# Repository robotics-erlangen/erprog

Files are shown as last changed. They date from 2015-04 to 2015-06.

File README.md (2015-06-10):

# ERPROG
This is a JTAG-Programmer developed by the Robot Soccer Team ER-Force from Erlangen, Germany.
The device is using a FTDI chip for communication and a digital isolator for the target.
All necessary files to build and control this device can be found within this repository.

The benefits of this hardware are the easy USB connection with EMC protection and over-current protection. Furthermore the standard JTAG output with a complete isolation up to 4kV. The target isolation is done by two ISO7231M from Texas Instruments. This device also does a voltage translation, which adapts to the target voltage-level. Working is guaranteed from 3.2 to 5.4V.
With this circuit the computer is never effected, if the programming target fails in any way.

Project origin: https://www.robotics-erlangen.de/publications/jtag-programmer

## Hardware

The PCB is designed with EAGLE. The schematic can be found in `erprog_1504-1.sch` and the board in `erprog_1504-1.brd`. The dimension of the PCB is 850mil x 2300mil.

The main ICs are

1.  FT4232HL does the USB to JTAG conversation
2.  ISO7231 is the digital isolator

## Software

The software readme is in https://github.com/robotics-erlangen/erprog/tree/master/software

## Computer connection

**via USB**

The device is connected via a Mini-USB plug to the computer.

## Target connection

**via JTAG**

This hardware uses a JTAG standard connector with a 10 pin connector with the `CoreSight 10` pinout.
Follwoing the pinout is described based on a standard 10 pin 100mil plug with 2 rows.

1.  VTREF
2.  TMS
3.  GND
4.  TCK
5.  GND
6.  TDO
7.  NC
8.  TDI
9.  GND
10. nSRST

## ToDo

For the next release it is planned to allow the controlling of the isolator's enable-pin. Thus, the programmer can be put into high-impedance mode so it does not interfere with the target in normal operation.

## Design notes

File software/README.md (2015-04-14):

# ERPROG Software

## Setup

**Build OpenOCD:**

1.	Download OpenOCD 0.8.0 (MD5 6d83c34763a5f1d1ac7ad83c5a11f4fb) and install `libusb-1.0`
2.	Build using:

	```
	mkdir build && cd build
	../configure --enable-ftdi --prefix=../build-out
	```

**On Linux:**

1.	Install the udev config file `udev/99-robotics-usb-devices.rules`
2.	Copy into the folder `/etc/udev/rules.d/`

**Embedded Compiler / Debugger:**
Get GCC 4.9 from https://launchpad.net/gcc-arm-embedded

**Create config files:**

1.	Create board file and flash configuration (see `board/*.cfg` and `flash/*.cfg`)
2.	Make sure to add

	```
	source [find interface/oocdlink-erforce2014.cfg]
	reset_config srst_only srst_nogate srst_push_pull
	```
	at the beginning

## Flashing     

*Tested on Linux and Mac OS X* 

1.	Connect connect the JTAG adapter with the board you want to flash and your USB port.
2.	Then run

	```
	cd JTAG-software
	${path/to/openocd} -c "debug_level 0" -s openocd -c "set ::ELF_FILE \"${path/to/elf-file}\"" -f flash/${CONFIG-NAME}.cfg
	```

**Troubleshooting:**
-	Check that the JTAG-adapter is connected to USB and the board
-	Check that the board is powered on
-	Check that the udev file (udev/99-robotics-usb-devices.rules) is installed
-	OpenOCD complains about "JTAG-DP OVERRUN" -> Resetting via SRST is not working, check that on the board JTAG SRST pin is connected with NRST pin of STM
-	Mac: „Error: libusb_claim_interface() failed with -3“. Run:
	```
	sudo kextunload -bundle com.apple.driver.AppleUSBFTDI
	```

## Debugging

*Only works on Linux*

1.	Flash the board with a build with **DEBUG symbols**!
2.	Start openocd for the board

	```
	cd JTAG-software
	${path/to/openocd} -c "debug_level 0" -s openocd -f board/${BOARD-NAME}.cfg
	```
3.	Connect to the debugger using Qt Creator:
	Debug > Start debugging > Attach to Remote Debug Server ...
	Set the following values:
	
	```
	Kit: Embedded
	Server port: 3333 (This attaches to the first cpu target, use 3334 for the second, ...)
	Local executable: the elf file in bin/firmware that was flashed
	```

The Kit has to be created before:

1.	Tools > Options ... > Build & Run > Kits
2.	Add a new kit with name `Embedded`, set device type to `Generic Linux Device`
3. 	Debugger > Edit...
	1. 	Path: `/usr/bin/arm-none-eabi-gdb`  (arm version of gdb with python), exectuable name could also be `arm-none-eabi-gdb-py`.
	2. 	Qt version: None

Have fun debugging! The debugger will attach to the running firmware. If you want
to debug the startup procedure, then edit the openocd configuration as described
in `openocd/board/all2014.cfg`

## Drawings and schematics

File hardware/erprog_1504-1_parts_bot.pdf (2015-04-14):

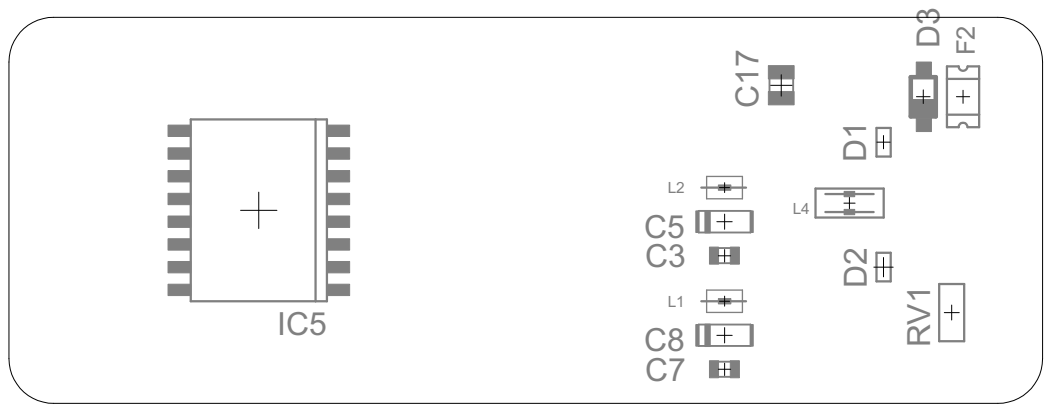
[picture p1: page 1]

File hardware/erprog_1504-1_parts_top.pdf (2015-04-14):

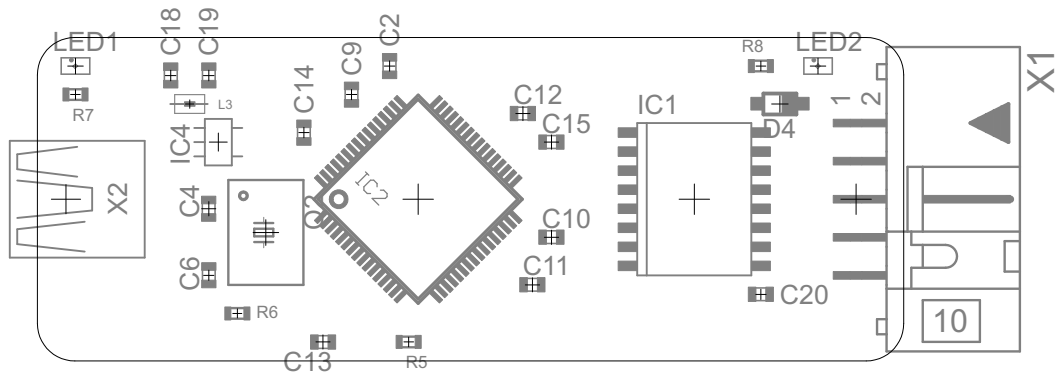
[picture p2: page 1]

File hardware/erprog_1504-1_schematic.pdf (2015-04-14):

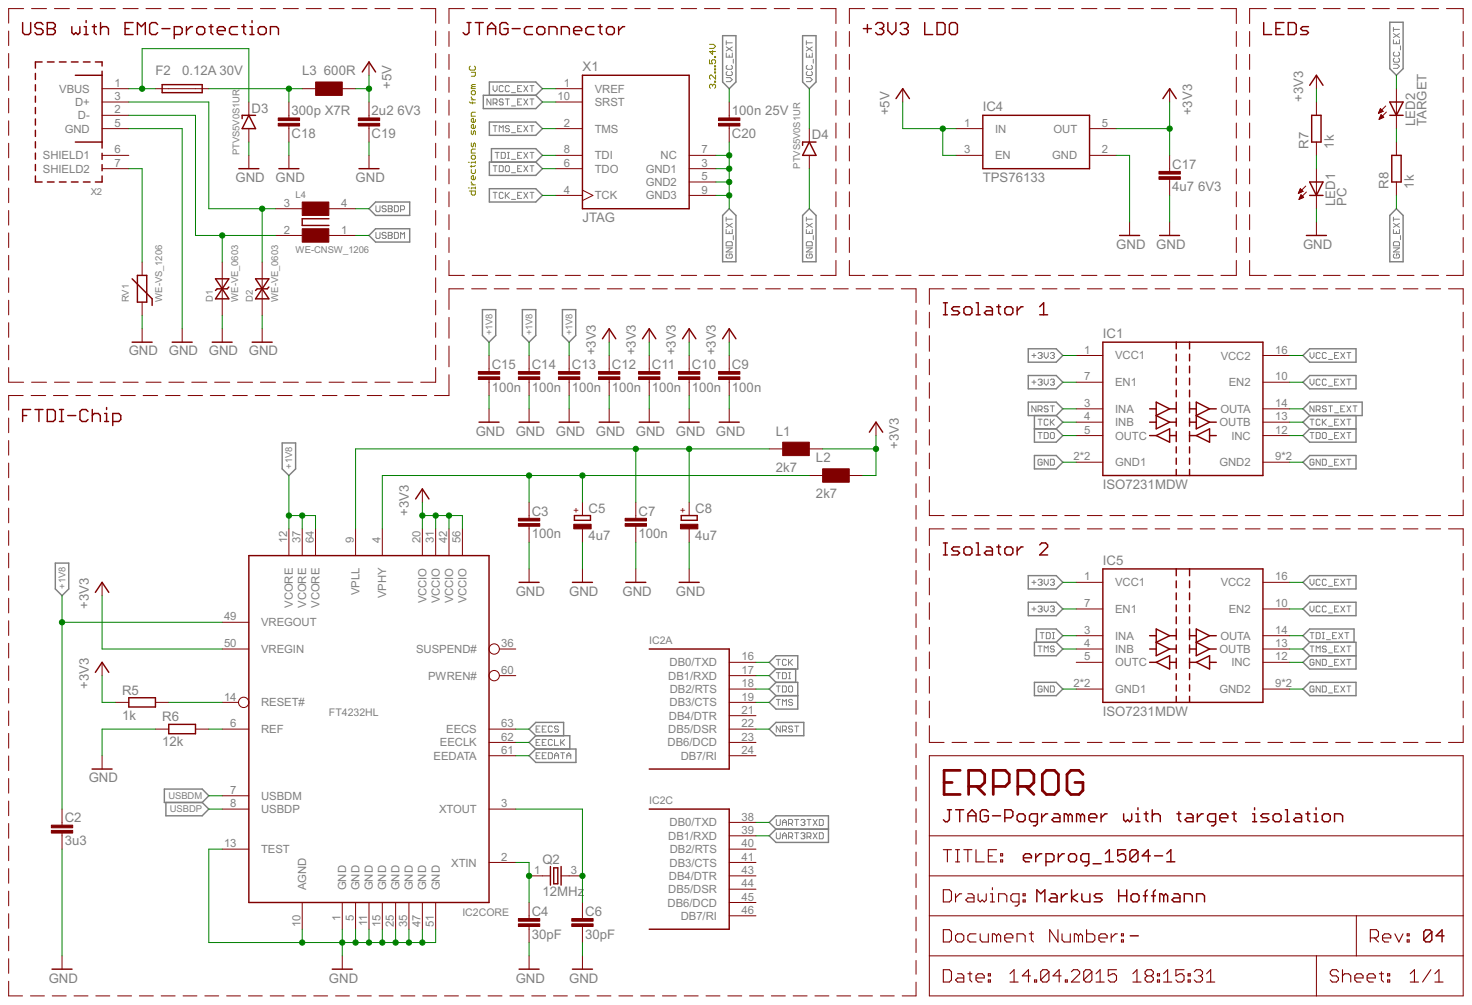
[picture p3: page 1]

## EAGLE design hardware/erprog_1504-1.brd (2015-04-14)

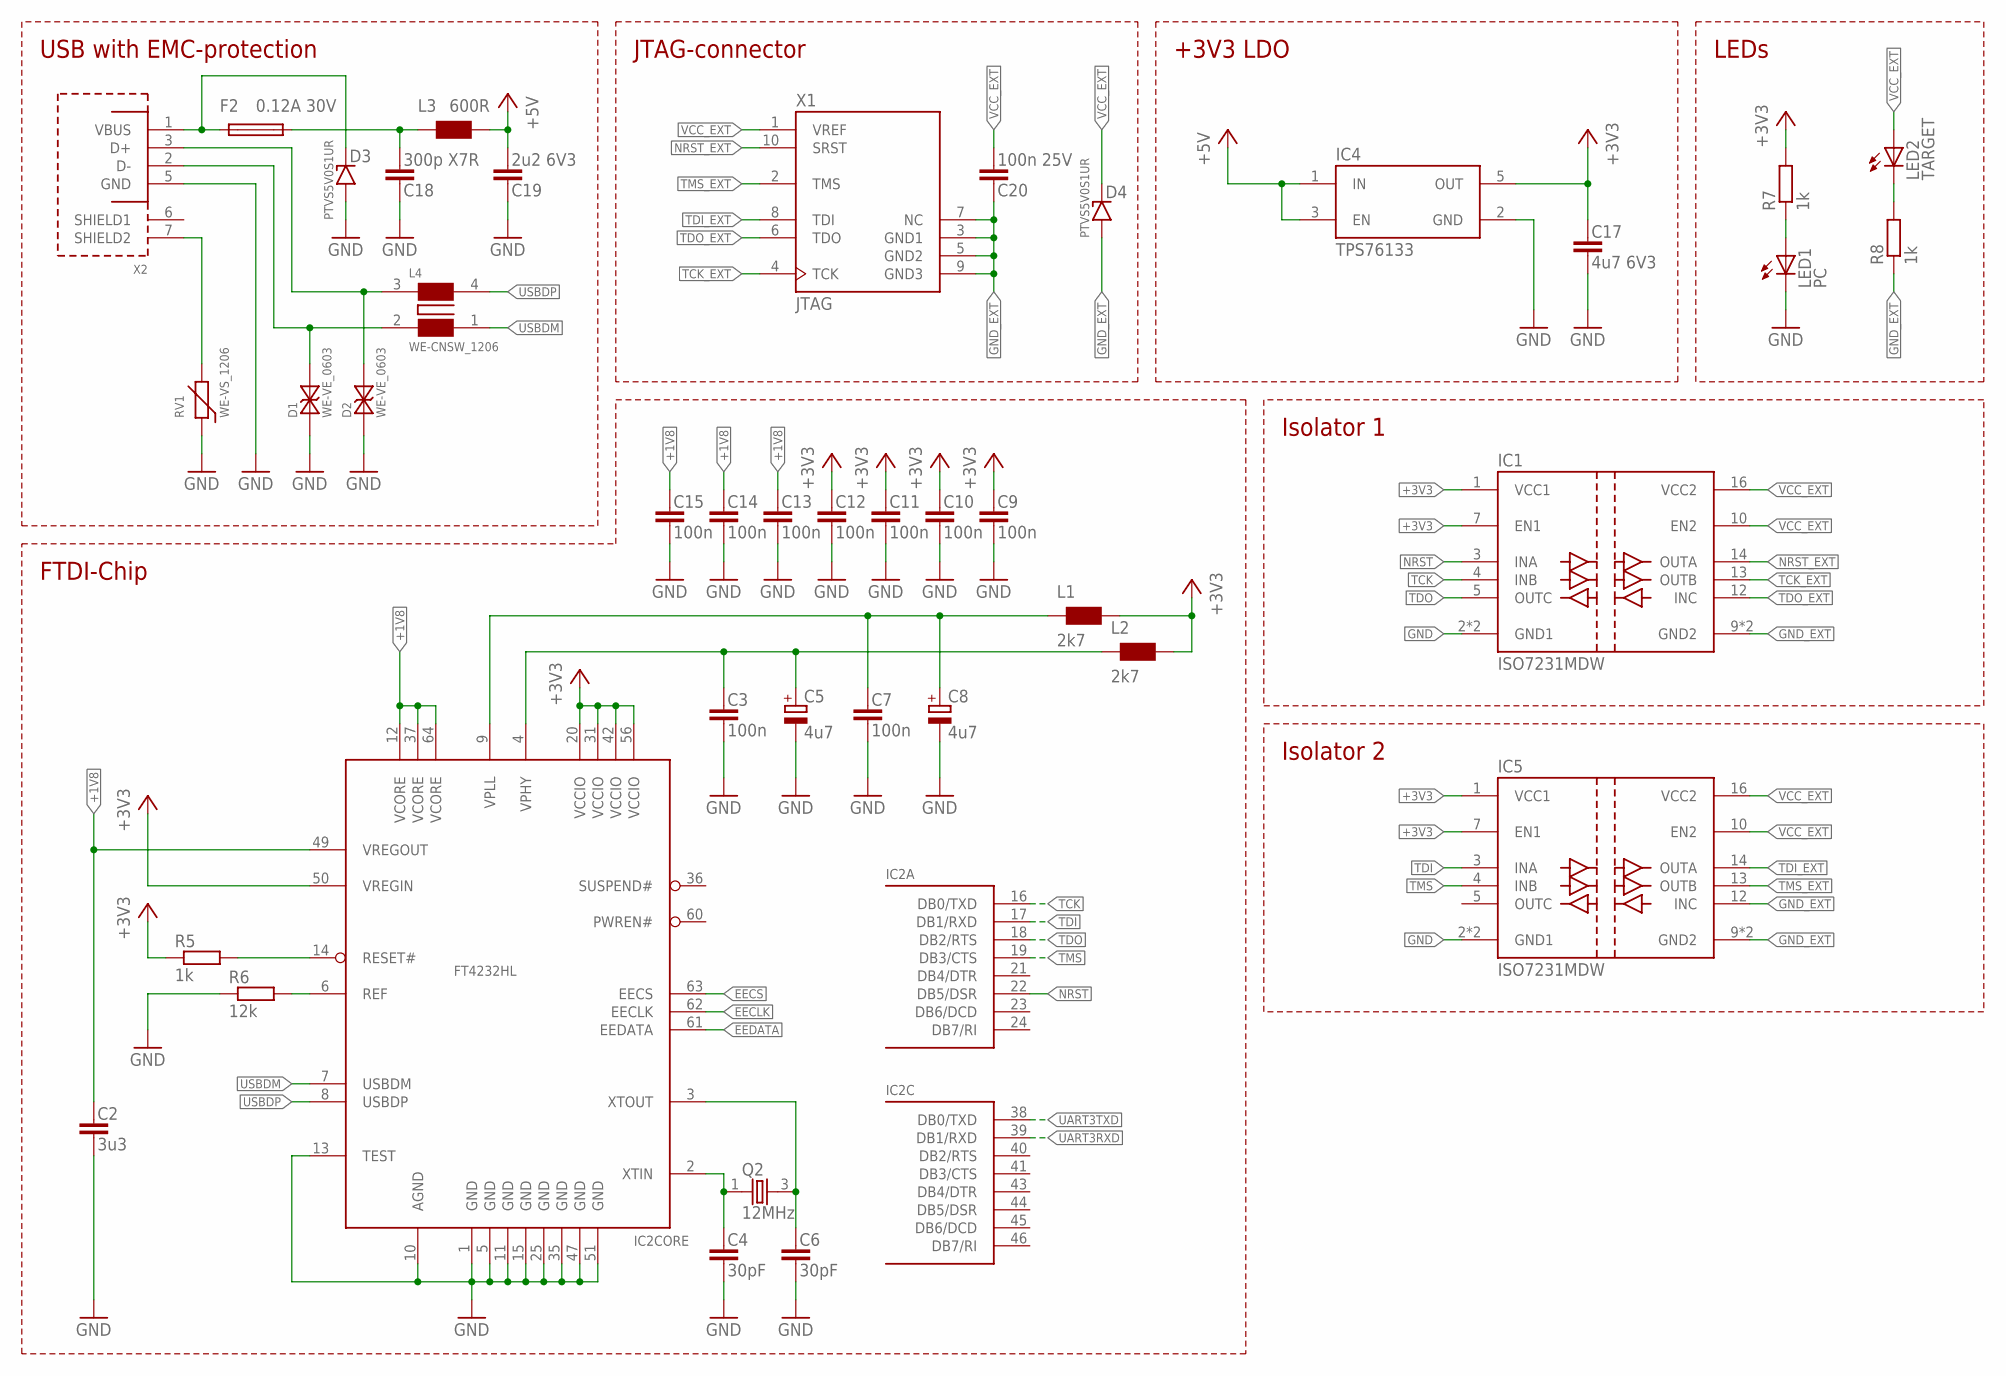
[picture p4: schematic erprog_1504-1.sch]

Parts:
C2: 3u3; C0603
C3, C7, C9, C10, C11, C12, C13, C14, C15: 100n; C0603
C4, C6: 30pF; C0603
C5, C8: 4u7; A/3216-18R
C17: 4u7 6V3; C0805
C18: 300p X7R; C0603
C19: 2u2 6V3; C0603
C20: 100n 25V; C0603
D1, D2: WE-VE_0603; WESURGE_0603
D3, D4: PTVS5V0S1UR; SOD123
F2: 0.12A 30V; MF-NSMF-1
IC1, IC5: ISO7231MDW; SO16_SOT162-1
IC2: FT4232HL; LQFP64
IC4: TPS76133; SOT-23-5
L1, L2: 2k7; 0805; FARNELL 1800366
L3: 600R; 0805
L4: WE-CNSW_1206
LED1: PC; SML0805
LED2: TARGET; SML0805
Q2: 12MHz; MQ
R5, R7, R8: 1k; R0603
R6: 12k; R0603
RV1: WE-VS_1206; WESURGE_1206
X1: JTAG; ML10R
X2: USB-SHIELD-MINI-B-BUCHSE-R-ASSMANN; USB-MINI-B-BUCHSE-R

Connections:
+1V8: C2.1, C13.1, C14.1, C15.1, IC2.12 (VCORE), IC2.37 (VCORE), IC2.49 (VREGOUT), IC2.64 (VCORE)
+3V3: C9.1, C10.1, C11.1, C12.1, C17.1, IC1.1 (VCC1), IC1.7 (EN1), IC2.20 (VCCIO), IC2.31 (VCCIO), IC2.42 (VCCIO), IC2.50 (VREGIN), IC2.56 (VCCIO), IC4.5 (OUT), IC5.1 (VCC1), IC5.7 (EN1), L1.2, L2.2, R5.1, R7.2
+5V: C19.2, IC4.1 (IN), IC4.3 (EN), L3.2
EECLK: IC2.62 (EECLK)
EECS: IC2.63 (EECS)
EEDATA: IC2.61 (EEDATA)
GND: C2.2, C3.2, C4.2, C5.-, C6.2, C7.2, C8.-, C9.2, C10.2, C11.2, C12.2, C13.2, C14.2, C15.2, C17.2, C18.1, C19.1, D1.2, D2.2, D3.A (ANODE), IC1.2 (GND1), IC1.8 (GND1), IC2.1 (GND), IC2.5 (GND), IC2.10 (AGND), IC2.11 (GND), IC2.13 (TEST), IC2.15 (GND), IC2.25 (GND), IC2.35 (GND), IC2.47 (GND), IC2.51 (GND), IC4.2 (GND), IC5.2 (GND1), IC5.8 (GND1), LED1.C, R6.1, RV1.1, X2.5 (GND)
GND_EXT: C20.1, D4.A (ANODE), IC1.9 (GND2), IC1.15 (GND2), IC5.9 (GND2), IC5.12 (INC), IC5.15 (GND2), R8.1, X1.3 (GND1), X1.5 (GND2), X1.7 (NC), X1.9 (GND3)
unnamed: D3.C (KATHODE), F2.1, X2.1 (VBUS)
unnamed: LED1.A, R7.1
unnamed: D1.1, L4.2, X2.2 (D-)
unnamed: RV1.2, X2.7 (SHIELD2)
unnamed: LED2.C, R8.2
unnamed: C18.2, F2.2, L3.1
unnamed: D2.1, L4.3 (4), X2.3 (D+)
unnamed: IC2.14 (RESET#), R5.2
unnamed: IC2.6 (REF), R6.2
unnamed: C3.1, C5.+, IC2.4 (VPHY), L2.1
unnamed: C7.1, C8.+, IC2.9 (VPLL), L1.1
unnamed: C6.1, IC2.3 (XTOUT), Q2.3 (2)
unnamed: C4.1, IC2.2 (XTIN), Q2.1
NRST: IC1.3 (INA), IC2.22 (DB5/DSR)
NRST_EXT: IC1.14 (OUTA), X1.10 (SRST)
TCK: IC1.4 (INB), IC2.16 (DB0/TXD)
TCK_EXT: IC1.13 (OUTB), X1.4 (TCK)
TDI: IC2.17 (DB1/RXD), IC5.3 (INA)
TDI_EXT: IC5.14 (OUTA), X1.8 (TDI)
TDO: IC1.5 (OUTC), IC2.18 (DB2/RTS)
TDO_EXT: IC1.12 (INC), X1.6 (TDO)
TMS: IC2.19 (DB3/CTS), IC5.4 (INB)
TMS_EXT: IC5.13 (OUTB), X1.2 (TMS)
UART3RXD: IC2.39 (DB1/RXD)
UART3TXD: IC2.38 (DB0/TXD)
USBDM: IC2.7 (USBDM), L4.1
USBDP: IC2.8 (USBDP), L4.4 (3)
VCC_EXT: C20.2, D4.C (KATHODE), IC1.10 (EN2), IC1.16 (VCC2), IC5.10 (EN2), IC5.16 (VCC2), LED2.A, X1.1 (VREF)

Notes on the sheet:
JTAG-connector
+3V3 LDO
LEDs
USB with EMC-protection
FTDI-Chip
Isolator 1
Isolator 2

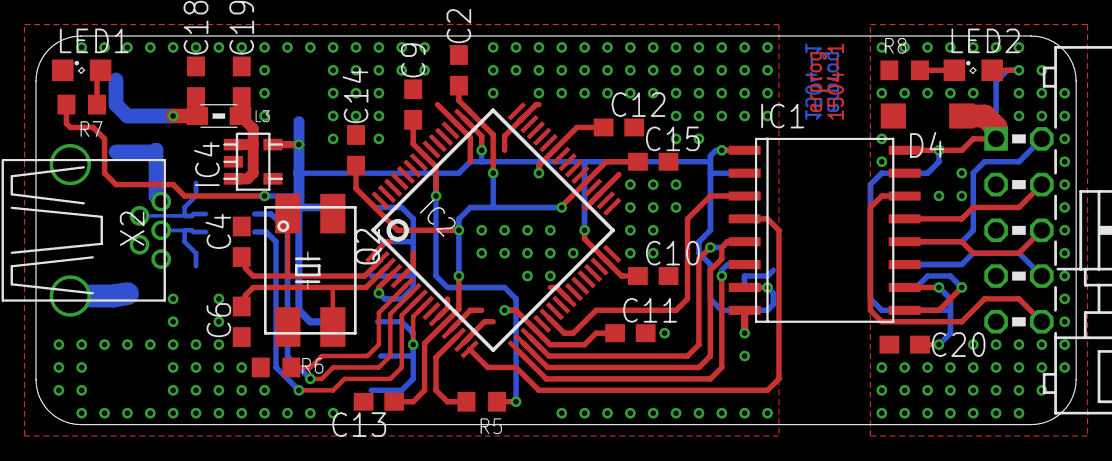
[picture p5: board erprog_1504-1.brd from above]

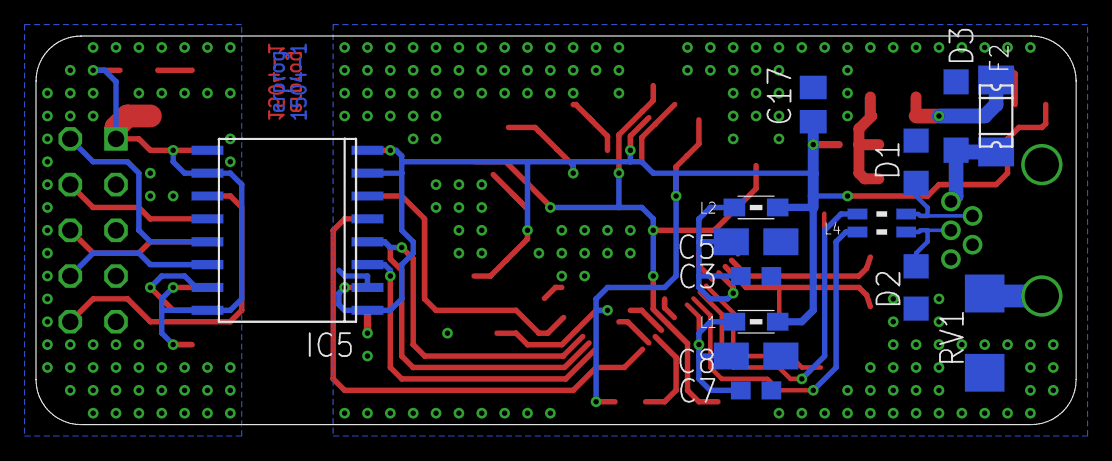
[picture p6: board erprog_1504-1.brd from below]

Board: 2 copper layers, 57.8 x 21.6 mm, 41 parts (14 on the bottom side), 31 nets.

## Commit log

2015-04-14 added openocd config files
    [all2014.cfg, common2014.cfg, kicker2014.cfg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]
2015-04-14 added board and schematic as EAGLE files
    [erprog_1504-1.brd, erprog_1504-1.sch]
2015-04-14 rearranged names of parts
    [erprog_1504-1.brd]
2015-04-14 added schematic and component diagram as pdfs

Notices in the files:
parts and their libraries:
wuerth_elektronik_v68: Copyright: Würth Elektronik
